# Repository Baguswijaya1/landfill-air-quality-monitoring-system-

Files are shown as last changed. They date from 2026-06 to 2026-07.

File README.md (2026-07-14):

# AQUOS - Air Quality Monitoring System

Repository ini adalah dokumentasi dan panduan penggunaan AQUOS (Air Quality Monitoring System), alat pemantau kualitas udara untuk area di sekitar tempat pembuangan sampah. Projek ini adalah Program Kerja KKN-PPM UGM di Desa Sumberrejo, Kecamatan Batur, Kabupaten Banjarnegara.

## ✨ Fitur Utama
- **Mendeteksi tiga jenis gas berbahaya** yang umum ditemui di tempat pembuangan sampah, seperti gas Metana (CH<sub>4</sub>), Amonia (NH<sub>3</sub>), dan Asam Sulfida (H<sub>2</sub>S).
- Pemantauan secara langsung lewat **LCD display** maupun melalui *smartphone* menggunakan **local dashboard**, sehingga bisa diakses di area sekitar alat.
- **Menggunakan sensor dan komponen biaya murah** (MQ2, MQ135, MQ135, ESP32).
- **Sistem yang dirancang modular**, memudahkan  penggantian sensor dan komponen apabila terjadi kerusakan.

## :exclamation:Disclaimer
- sensor gas dalam AQUOS memiliki tingkat kepekaan yang rendah, sehingga tidak dapat mendeteksi perbedaan kadar gas secara signifikan.
- hasil bacaan sensor hanya mewakili tingkat keberbahayaan gas berdasarkan sinyal dari sensor, bukan kadar gas yang sebenarnya dalam satuan yang akurat (ppm, %)

# :orange_book:Panduan Penggunaan Alat
### :battery: Menyalakan AQUOS
1. Hubungkan port USB tipe micro-B pada alat dengan sumber tenaga dengan tegangan 5V dan daya 25W. 
2. Anda bisa mentenagai alat menggunaakan adaptor charger smartphone 25W ke stop kontak rumah/gedung.
3. Alat akan aktif dan mulai mengambil data gas di lingkungan sekitar. 
4. Tunggu 30 menit untuk mendapat data sensor yang lebih akurat, karena sensor membutuhkan penyesuaian terlebih dahulu setelah dinyalakan

### :desktop_computer: Memantau kualitas udara lewat LCD
1. Hasil pengukuran tingkat kepekatan gas dapat dilihat langsung pada layar LCD.

### :signal_strength: Memantau Kualitas Udara Melalui *Smartphone*/Komputer dengan *Local Dashboard*
AQUOS tidak memerlukan akses internet untuk bisa dipantau lewat perangkat pribadi. Sebaliknya, alat ini berperan sebagai *access point*, dan data sensor dapat diakses dengan menghubungkan perangkat pribadi dengan koneksi alat dan masuk ke alamat IP alat lewat aplikasi *browser*. Berikut ini adalah langkah-langkahnya.
1. **Nyalakan alat**
2. **Siapkan perangkat pribadi** (smartphone/komputer) dan **hubungkan dengan jaringan yang disediakan oleh AQUOS**.
```
SSID = AQUOS-Batur
Password = batur123
```
SSID dan password dapat dikustomisasi dengan mengubah kode program di *aquos_code/include/access_point.h* 

4. **Buka aplikasi browser** lalu pergi ke alamat IP dari AQUOS dengan mengetik **192.168.4.1** pada panel penelusuran
5. Sekarang kamu bisa melihat kualitas udara saat ini. **Refresh halaman browser** untuk mendapatkan pembaruan data.

# Perawatan dan Pengembangan
## :hammer_and_wrench: Komponen Utama
| Nama Komponen | Fungsi | 
|:---|:---:|
| ESP32 DevKit V1 | Microcontroller sebagai Unit Pemroses Utama |
| MQ2 | Sensor Gas Metana (CH<sub>4</sub>) |
| MQ135 | Sensor Gas Amonia (NH<sub>3</sub>) |
| MQ136 | Sensor Gas Asam Sulfida (H<sub>2</sub>S) |
| LCD 16x2 | Komponen untuk menampilkan bacaan sensor |
| Modul TXS0108E | Logic Level Shifter untuk konversi tegangan data keluar dan masuk ESP32|
</div>

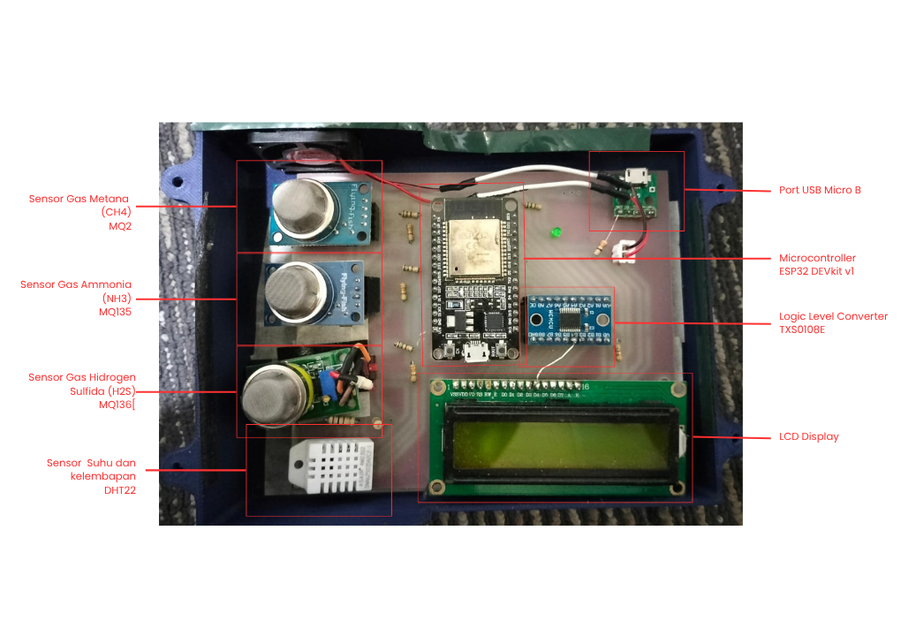
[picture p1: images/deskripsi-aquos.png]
deskripsi-aquos


## :construction: Struktur Projek

Projek ini terdiri dari tiga bagian utama:
* **aquos_code**: berisi kode program dari projek ini. Dibuat menggunakaan Arduino Framework dan PlatformIO.
* **aquos_pcb**: berisi desain PCB dari projek ini. Dapat dibuka menggunakan software KiCad 12.0.
* **aquos_chasing**: berisi desain chasing dari projek ini. Dibuat menggunakan Autodesk Inventor.

## :computer: Pengembangan
Projek ini adalah projek open-source. Anda bebas untuk menggunakan repository ini untuk projek Anda ataupun untuk pengembangan lebih lanjut.

```
git clone https://github.com/Baguswijaya1/landfill-air-quality-monitoring-system-.git
```
Untuk diskusi lebih lanjut, Anda dapat melakukan kontak dengan saya melalui email bagusanw@gmail.com

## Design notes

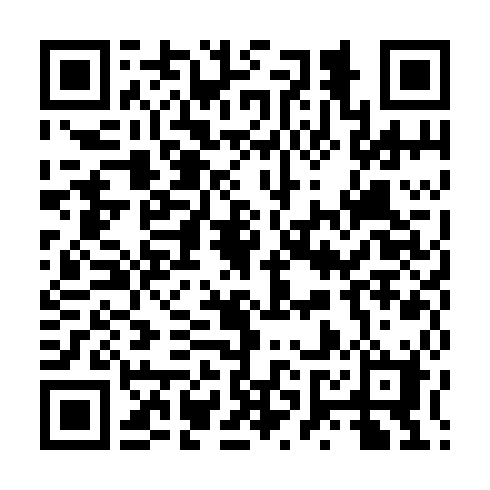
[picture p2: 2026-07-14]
images/panduan-lengkap.png

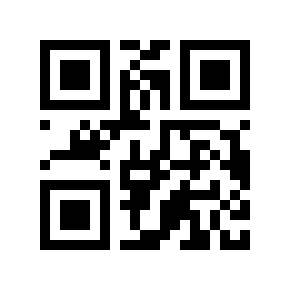
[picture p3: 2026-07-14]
images/pantau.png

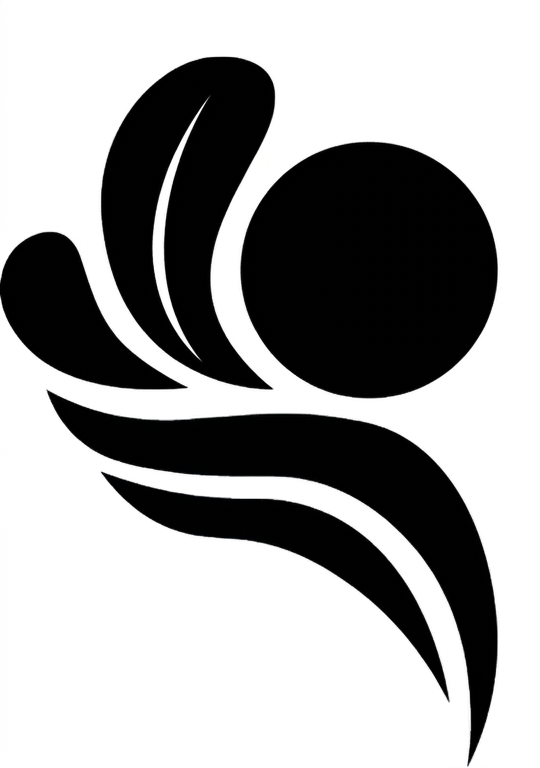
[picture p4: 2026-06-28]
aquos_pcb/Gemini_Generated_Image_mbq0v3mbq0v3mbq0.png

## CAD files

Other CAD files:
aquos_chasis/Assembly1.iam
aquos_chasis/OldVersions/Assembly1.0001.iam
aquos_chasis/OldVersions/base.0004.ipt
aquos_chasis/OldVersions/top.0002.ipt
aquos_chasis/base.ipt
aquos_chasis/top.ipt

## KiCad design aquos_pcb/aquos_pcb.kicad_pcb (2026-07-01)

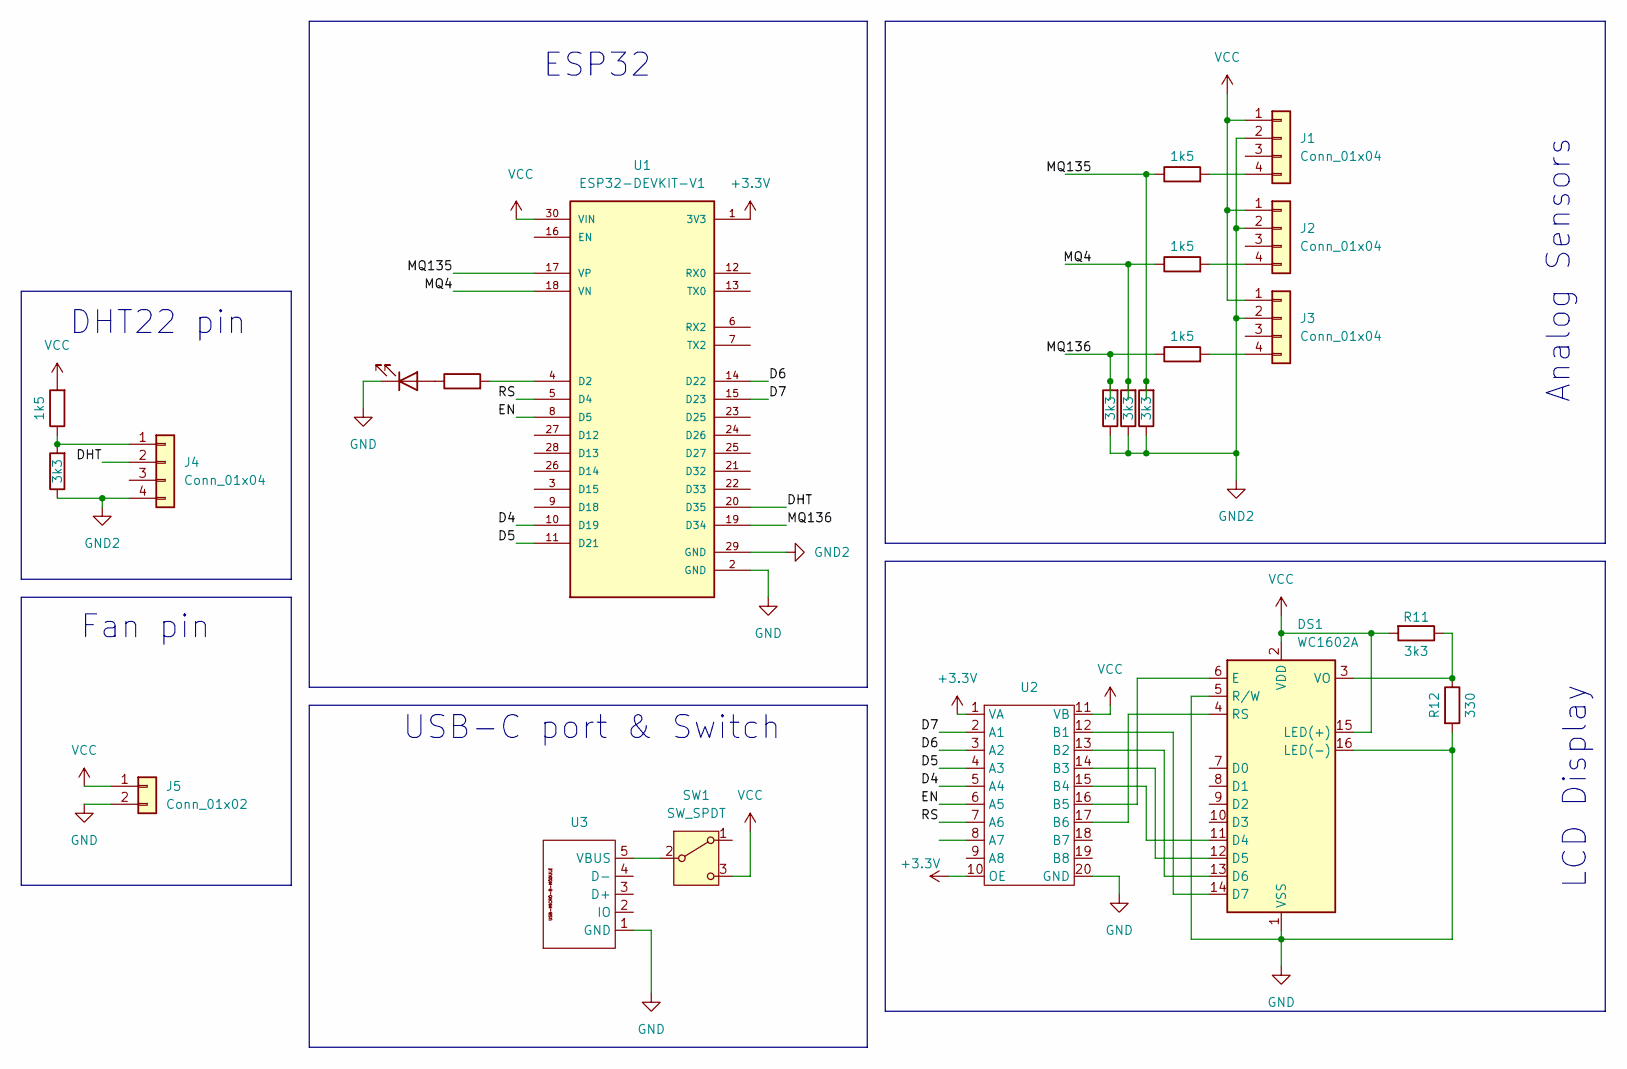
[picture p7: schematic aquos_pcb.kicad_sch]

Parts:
D1: LED; LED_D3.0mm_FlatTop
DS1: WC1602A
J1, J2, J3, J4: Conn_01x04; PinHeader_1x04_P2.54mm_Vertical
J5: Conn_01x02; PinHeader_1x02_P2.54mm_Vertical
R1: R; R_Axial_DIN0204_L3.6mm_D1.6mm_P5.08mm_Horizontal
R5, R6, R7, R13: 1k5; R_Axial_DIN0204_L3.6mm_D1.6mm_P5.08mm_Horizontal
R8, R9, R10, R11, R14: 3k3; R_Axial_DIN0204_L3.6mm_D1.6mm_P5.08mm_Horizontal
R12: 330; R_Axial_DIN0204_L3.6mm_D1.6mm_P5.08mm_Horizontal
SW1: SW_SPDT; SW_Slide-03_Wuerth-WS-SLTV_10x2.5x6.4_P2.54mm
U1: ESP32-DEVKIT-V1; MODULE_ESP32_DEVKIT_V1; PARTREV N/A
U2: TXE0108E; txs0108e module
U3: USB-MICRO-B-MODULE

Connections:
+3.3V: U1.1 (3V3), U2.1 (VA), U2.10 (OE)
/D4: U1.10 (D19), U2.5 (A4)
/D5: U1.11 (D21), U2.4 (A3)
/D6: U1.14 (D22), U2.3 (A2)
/D7: U1.15 (D23), U2.2 (A1)
/DHT: J4.2, U1.20 (D35)
/EN: U1.8 (D5), U2.6 (A5)
/MQ4: R6.1, R9.2, U1.18 (VN)
/MQ135: R5.1, R10.2, U1.17 (VP)
/MQ136: R7.1, R8.2, U1.19 (D34)
/RS: U1.5 (D4), U2.7 (A6)
GND: D1.1 (K), DS1.1 (VSS), DS1.5 (R/W), DS1.16 (LED(-)), J5.2, R12.2, U1.2 (GND), U2.20 (GND), U3.1 (GND)
GND2: J1.2, J2.2, J3.2, J4.4, R8.1, R9.1, R10.1, R14.1, U1.29 (GND)
unnamed: D1.2 (A), R1.1
unnamed: DS1.11 (D4), U2.15 (B4)
unnamed: DS1.12 (D5), U2.14 (B3)
unnamed: DS1.13 (D6), U2.13 (B2)
unnamed: DS1.14 (D7), U2.12 (B1)
unnamed: DS1.6 (E), U2.16 (B5)
unnamed: DS1.4 (RS), U2.17 (B6)
unnamed: DS1.3 (VO), R11.1, R12.1
unnamed: J1.4, R5.2
unnamed: J2.4, R6.2
unnamed: J3.4, R7.2
unnamed: J4.1, R13.1, R14.2
unnamed: SW1.2 (B), U3.5 (VBUS)
unnamed: R1.2, U1.4 (D2)
VCC: DS1.2 (VDD), DS1.15 (LED(+)), J1.1, J2.1, J3.1, J5.1, R11.2, R13.2, SW1.3 (C), U1.30 (VIN), U2.11 (VB)

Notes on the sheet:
LCD Display
USB-C port & Switch
ESP32
Fan pin
DHT22 pin
Analog Sensors

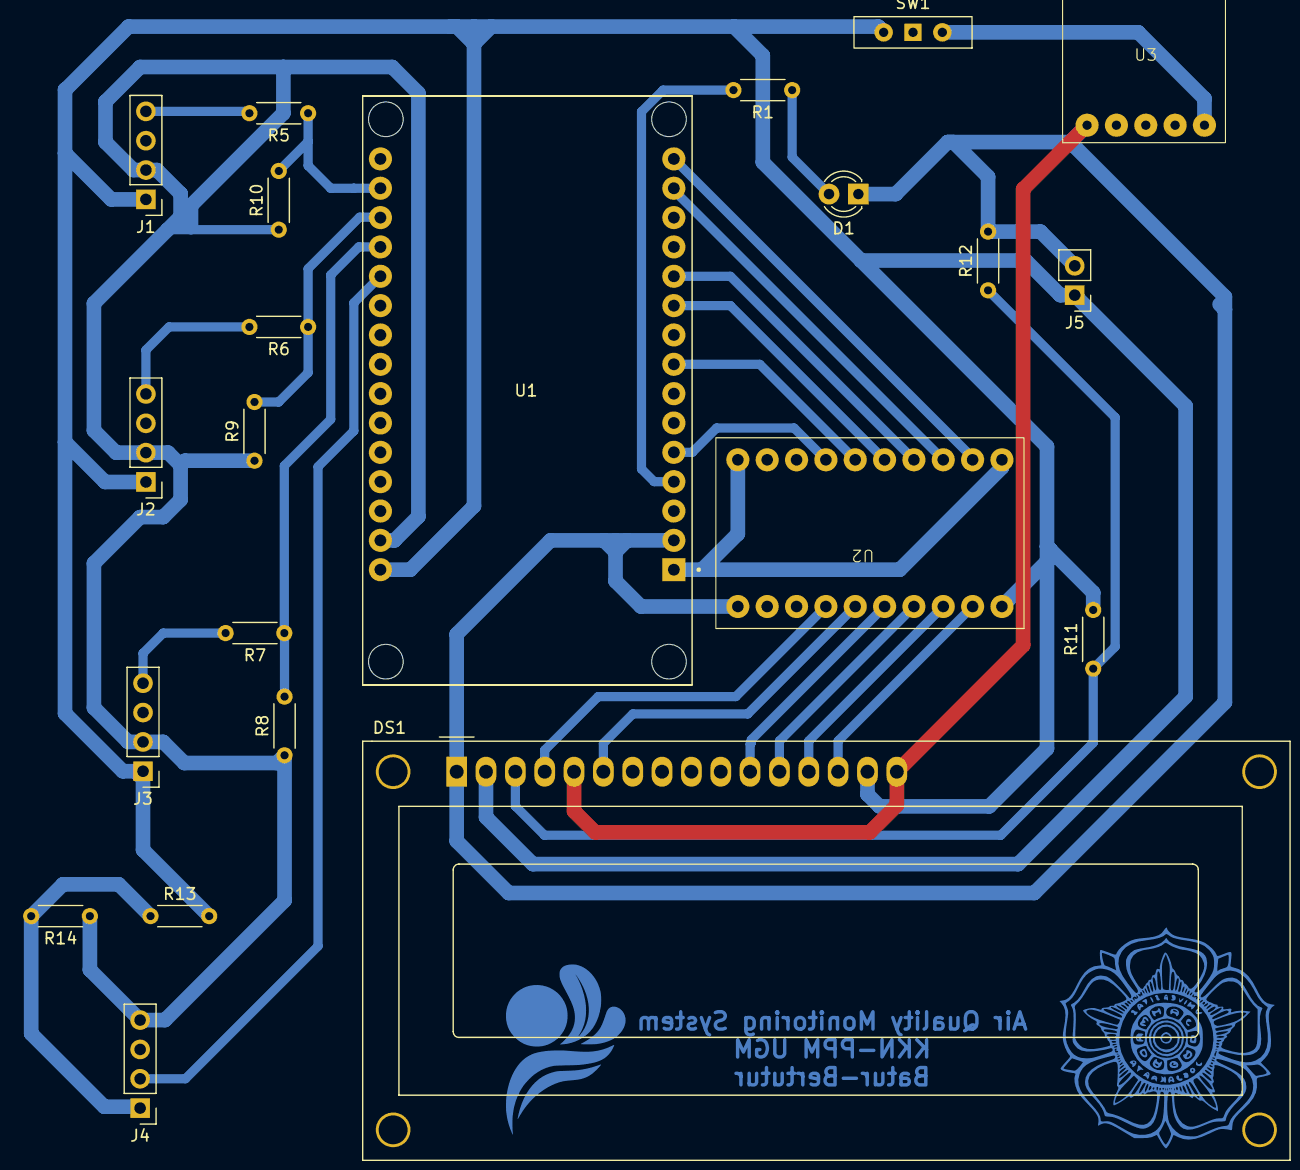
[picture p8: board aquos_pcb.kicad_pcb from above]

Board: 2 copper layers, 22 parts (0 on the bottom side), 28 nets.

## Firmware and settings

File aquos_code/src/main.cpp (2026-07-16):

#include <Arduino.h>
#include <vector>
#include <sensor.h>
#include <display.h>
#include <access_point.h>
#include <web_server_dashboard.h>

Sensor MQ4;
Sensor MQ135;
Sensor MQ136;
Sensor humidity;
Sensor temperature;


const int display_delay = 2000;
unsigned long prevTime = 0;
int counter = 0;

void setup() {
  // Serial.begin(9600);
  Serial.println("starting sensor");
  setup_display();
  setup_sensors();

  setup_access_point();
  setup_webserver();
}

void loop() {
  unsigned long currentTime = millis();
  MQ4.measured_value = readSensor(mq4_pin, MQ4.tempval, MQ4.buffer, MQ4.prev_value);
  MQ135.measured_value = readSensor(mq135_pin, MQ135.tempval, MQ135.buffer, MQ135.prev_value);
  MQ136.measured_value = readSensor(mq136_pin, MQ136.tempval, MQ136.buffer, MQ136.prev_value);
  sensors_event_t event;

  MQ4.status = decide_status(MQ4.measured_value, ch4_threshold);
  MQ135.status = decide_status(MQ135.measured_value, nh3_threshold);
  MQ136.status = decide_status(MQ136.measured_value, h2s_threshold);

  sensor_mq4 = change_to_scale(MQ4.measured_value);
  sensor_mq135 = change_to_scale(MQ135.measured_value);
  sensor_mq136 = change_to_scale(MQ136.measured_value);
  // sensor_humidity = humidity.measured_value;
  // sensor_humidity = 0;
  sensor_temperature = temperature.measured_value;
  sensor_mq4_status = MQ4.status;
  sensor_mq135_status = MQ135.status;
  sensor_mq136_status = MQ136.status;

  if (currentTime - prevTime >= display_delay){
    prevTime = currentTime;
    // humidity.measured_value = readHumidity();
    // temperature.measured_value = readTemperature();
    // counter += 1;
    lcd_display_page1(sensor_mq4, sensor_mq136);
    // if (counter % 2 == 0){
    //   lcd_display_page1(MQ4.measured_value, MQ136.measured_value);
    // }  else {
    //   lcd_display_page2(temperature.measured_value, humidity.measured_value);
    // }
  }
    
  
  // serial_display(MQ4.measured_value, MQ135.measured_value, MQ136.measured_value, humidity.measured_value, temperature.measured_value);
  // display_sensor(MQ4.measured_value, MQ135.measured_value, MQ136.measured_value, humidity.measured_value);


  handle_webserver();
}

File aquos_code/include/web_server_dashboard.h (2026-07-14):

#ifndef WEB_SERVER_DASHBOARD_H
#define WEB_SERVER_DASHBOARD_H

#include <Arduino.h>
#include <WebServer.h>

WebServer server(80);

// Sensor values and statuses are updated from main.cpp
float sensor_mq4 = 0;
float sensor_mq135 = 0;
float sensor_mq136 = 0;
float sensor_humidity = 0;
float sensor_temperature = 0;
String sensor_mq4_status = "AMAN";
String sensor_mq135_status = "AMAN";
String sensor_mq136_status = "AMAN";

String status_class(const String& status) {
    if (status == "AMAN") {
        return "safe";
    }
    if (status == "SEDANG") {
        return "warning";
    }
    return "danger";
}

void handle_root() {
    String mq4_class = status_class(sensor_mq4_status);
    String mq135_class = status_class(sensor_mq135_status);
    String mq136_class = status_class(sensor_mq136_status);

    String html = "<!DOCTYPE html><html><head><title>Aquos Sensor Dashboard</title>";
    html += "<meta name='viewport' content='width=device-width, initial-scale=1'>";
    html += "<style>";
    html += "body { font-family: Arial, sans-serif; text-align: center; padding: 20px; }";
    html += ".sensor { display: inline-block; margin: 10px; padding: 15px; border: 1px solid #ccc; border-radius: 8px; min-width: 220px; }";
    html += ".value { font-size: 24px; font-weight: bold; color: #0066cc; }";
    html += ".safe { color: #1b8f3a; font-weight: bold; }";
    html += ".warning { color: #d4a400; font-weight: bold; }";
    html += ".danger { color: #d11f1f; font-weight: bold; }";
    html += ".status-label { margin-top: 8px; font-size: 18px; }";
    html += "</style></head><body>";
    html += "<h1>Sensor Dashboard</h1>";

    html += "<div class='sensor'><p>Metana (CH4): <span class='value'>";
    html += String(sensor_mq4, 2);
    html += "</span></p><p class='status-label'>Status: <span class='";
    html += mq4_class;
    html += "'>";
    html += sensor_mq4_status;
    html += "</span></p></div>";

    html += "<div class='sensor'><p>Ammonia (NH3): <span class='value'>";
    html += String(sensor_mq135, 2);
    html += "</span></p><p class='status-label'>Status: <span class='";
    html += mq135_class;
    html += "'>";
    html += sensor_mq135_status;
    html += "</span></p></div>";

    html += "<div class='sensor'><p>Hidrogen Sulfida (H2S): <span class='value'>";
    html += String(sensor_mq136, 2);
    html += "</span></p><p class='status-label'>Status: <span class='";
    html += mq136_class;
    html += "'>";
    html += sensor_mq136_status;
    html += "</span></p></div>";
    
    // html += "<div class='sensor'><p>Kelembapan: <span class='value'>";
    // html += String(sensor_humidity, 2);
    // html += "%</span></p></div>";
    
    // html += "<div class='sensor'><p>Suhu: <span class='value'>";
    // html += String(sensor_temperature, 2);
    // html += "C</span></p></div>";

    html += "</body></html>";
    server.send(200, "text/html", html);
}

void setup_webserver() {
    server.on("/", handle_root);
    server.begin();
    Serial.println("Web Server started");
}

void handle_webserver() {
    server.handleClient();
}

#endif

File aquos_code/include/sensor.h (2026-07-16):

#ifndef SENSOR_H
#define SENSOR_H

#include <Arduino.h>
#include <DHT.h>
#include <DHT_U.h>

#define mq4_pin 36
#define mq135_pin 39
#define mq136_pin 34
#define dht22_pin 35

#define DHTTYPE DHT22

float divider = 5.0f;
DHT_Unified dht(dht22_pin, DHTTYPE);
// // in analog read
// gas status limit
// float ch4_threshold = 513.0f;
// float nh3_threshold = 1;
// float h2s_threshold = 581.0f;

// scaled to /15
float ch4_threshold = 34.20;
float nh3_threshold = 1;
float h2s_threshold = 38.733f;

struct Sensor
{
    int buffer = 0;
    float tempval = 0.0f;
    float measured_value = 0.0f;    
    float prev_value = 0.0f;
    String status;
};

float movingAvg(float& storedVal, int& buffer, float value, float& prev_value){
    if (buffer < divider){
        storedVal += value;
        buffer += 1;
        return prev_value;
    } else if (buffer == divider){
        buffer = 0;
        float final_value = storedVal / divider;
        storedVal = 0;
        prev_value = final_value;
        return final_value;
    }
    return prev_value;
}

float readSensor(const int pin, float& storedVal, int& buffer, float& prev_value){
    float value = analogRead(pin);
    float filtered = movingAvg(storedVal, buffer, value, prev_value);
    return filtered;
}

String decide_status(float sensor_value, float hazard_threshold){
    String status;  
    if (sensor_value < hazard_threshold){
        status = "AMAN";
    } else {
        status = "BURUK";
    }
    return status;
}

void setup_sensors(){
    // analogSetPinAttenuation(mq4_pin, ADC_11db);
    analogSetPinAttenuation(mq135_pin, ADC_11db);
    // analogSetPinAttenuation(mq136_pin, ADC_11db);
    dht.begin();
}

float readHumidity(){
    sensors_event_t event;
    dht.temperature().getEvent(&event);
    if (isnan(event.temperature)){
        Serial.println("error reading temperature");
        return 0.1;
    } else {
        return event.temperature;
    }
}

float readTemperature(){
    sensors_event_t event;
    dht.humidity().getEvent(&event);
    if (isnan(event.relative_humidity)){
        Serial.println("error reading humidity");
        return 0.1;
    } else{
        return event.relative_humidity;
    }
}

float change_to_scale(float value){
    return value/15;
}



#endif

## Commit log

2026-06-10 rearange lcd pin
2026-06-12 rearrange lcd pin
2026-06-12 load PCB design
    [aquos_pcb.kicad_pcb, aquos_pcb.kicad_sch]
2026-06-27 ready to print
    [aquos_pcb.kicad_pcb, aquos_pcb.kicad_sch]
2026-07-01 create chasis design
    [Assembly1.0001.iam, Assembly1.iam, aquos_pcb.kicad_pcb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]
2026-07-16 change sensor threshold and add scaling
